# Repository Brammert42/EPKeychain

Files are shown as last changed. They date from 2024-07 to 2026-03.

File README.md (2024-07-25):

# DisplayKeychain
This repository is used to track FW development for Display Keychain using a RP2040 and waveshare Display.

# Manual
## Next image  
Holding the middle button for 4 seconds changes the image on the display to next image in the list.
347458965-2d2ebbd9-4378-4e5e-b3c1-cca8a8e5ecf9

## Previous image
Holding the middle button and the left button (button closet to the small hole) for 4 seconds changes the image on the display to previous image in the list.
347459136-833cc375-673a-45cc-b46e-be061921ad6f

## Uploading new FW  
Get the FW files here:   https://github.com/Brammert42/EPKeychain/tree/main/FW%20version
1: insert push pin in the hole next to the "previous" button untill you feel a "click"  
2: while the push pin is inserted insert the micro USB.  
3: on your PC the keychain will show up as flash drive as RPI-RP2, drag the new FW file into this  
347462579-89d27679-47dc-4f86-8ac1-4f59785b6a21
347464186-8c0baafe-d529-45a7-bd64-d2fc7caff128
347464487-d523694f-2f7c-4718-9145-aeae9413a095

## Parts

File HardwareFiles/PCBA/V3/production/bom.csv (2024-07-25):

Designator | Footprint | Quantity | Value | LCSC Part #
C1, C17, C18, C19, C21, C23, C24, C25, C26, C27, C28, C31, C7 | 0402 | 13 | 100n | C307331
C10, C11, C12, C20, C22, C3, C32, C33, C4, C5, C6, C8, C9 | 0402 | 13 | 1uF | C52923
C13, C14 | 0402 | 2 | 15p | C1548
C15, C16, C2, C29, C30, C34, C35, C36, C37, C38, C39, C40, C41, C42, C43, C44, C45, C46, C47, C48, C49 | 0402 | 21 | 10u | C23733
D1, D2, D3 | D_SOD-123 | 3 | MBR0530 | C8598
D4, D5 | D_SOD-923 | 2 | ESD9B3.3ST5G | C3021104
D6 | D_SOD-323 | 1 | LBAT54HT1G | C12744
J11 | BatteryHolder_Multicomp_BC-2001_1x2032 | 1 | BAT-HLD-001-THM | C2979177
J2 | Hirose_FH12-24S-0.5SH_1x24-1MP_P0.50mm_Horizontal | 1 | Conn_01x24 | C262669
J5 | USB_Micro-B_Wuerth_614105150721_Vertical | 1 | USB_B_Micro | C668588
L1 | 1210 | 1 | 68uH | C295164
Q1, Q3 | SOT-23 | 2 | AO3400A | C20917
Q2 | SOT-23 | 1 | AO3401A | C15127
R1, R10, R13, R14 | 0402 | 4 | 10k | C25744
R11, R9 | 0402 | 2 | 47k | C25792
R2 | 0402 | 1 | 3 | C321178
R4, R6 | 0402 | 2 | 1k | C11702
R5 | 0402 | 1 | DNF | dnf
R7, R8 | 0402 | 2 | 27 | C25100
SW1, SW3, SW6 | SW_SPST_Omron_B3FS-100xP | 3 | SW_Omron_B3FS | C5127964
SW2 | SW_SPST_TL3342 | 1 | SW_MEC_5E | C318884
TP1 | display | 1 | TestPoint | dnf
U1 | SOT-23-5 | 1 | MCP1802x-xx02xOT | C7419952
U4 | SON50P300X200X60-9N | 1 | ZD25WQ32CEIGR | C5258281
U5 | QFN-56-1EP_7x7mm_P0.4mm_EP3.2x3.2mm | 1 | RP2040 | C2040
Y1 | Crystal_SMD_3225-4Pin_3.2x2.5mm | 1 | ABM8-272-T3 | C9002

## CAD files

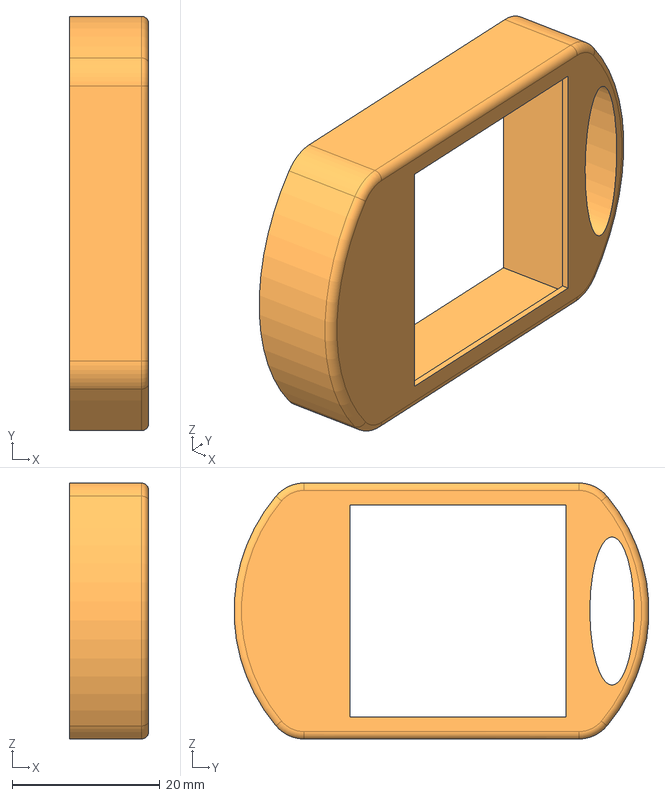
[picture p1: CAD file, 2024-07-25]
HardwareFiles/Enclosure/mainbody.step
10.8 x 56.1 x 34.6 mm

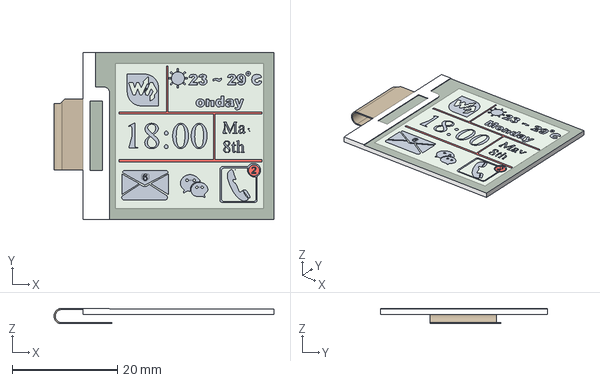
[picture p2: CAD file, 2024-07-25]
HardwareFiles/Enclosure/E-ink display.step
41.8 x 31.8 x 2.92 mm

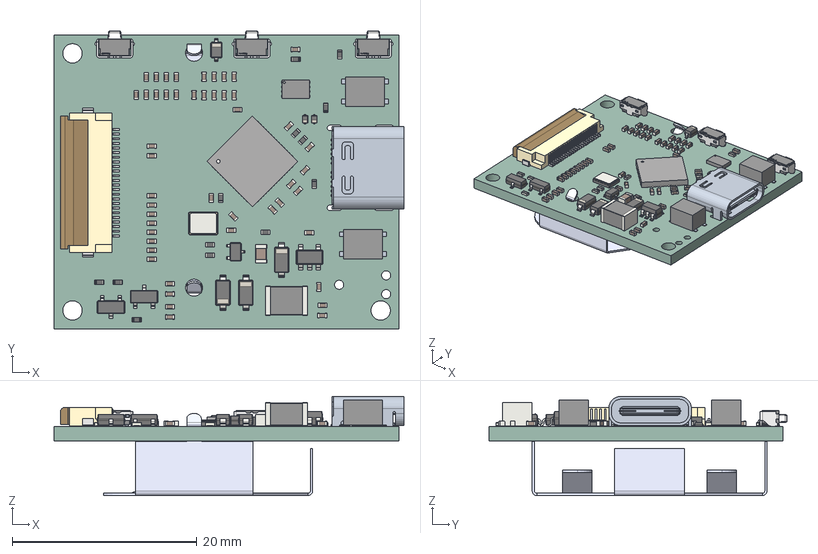
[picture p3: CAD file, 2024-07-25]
HardwareFiles/PCBA/V3/KeyChainv2.step
37.8 x 32.2 x 10.7 mm
C_0402_1005Metric x 48
R_0402_1005Metric x 13
D_SOD_923 x 2
SOT_323_SC_70
D_SOD_123 x 3
ASSEMBLY x 3
D_SOD_323
C_0805_2012Metric
QFN_56_1EP_7x7mm_P04mm_EP32x32mm
SOT_23 x 2
SOT_23_5
Hirose_FH12_xxS_0_5SH_Parametric_v0_1
L_1812_4532Metric
Crystal_SMD_3225-4Pin_3.2x2.5mm
_autosave-KeyChain_PCB

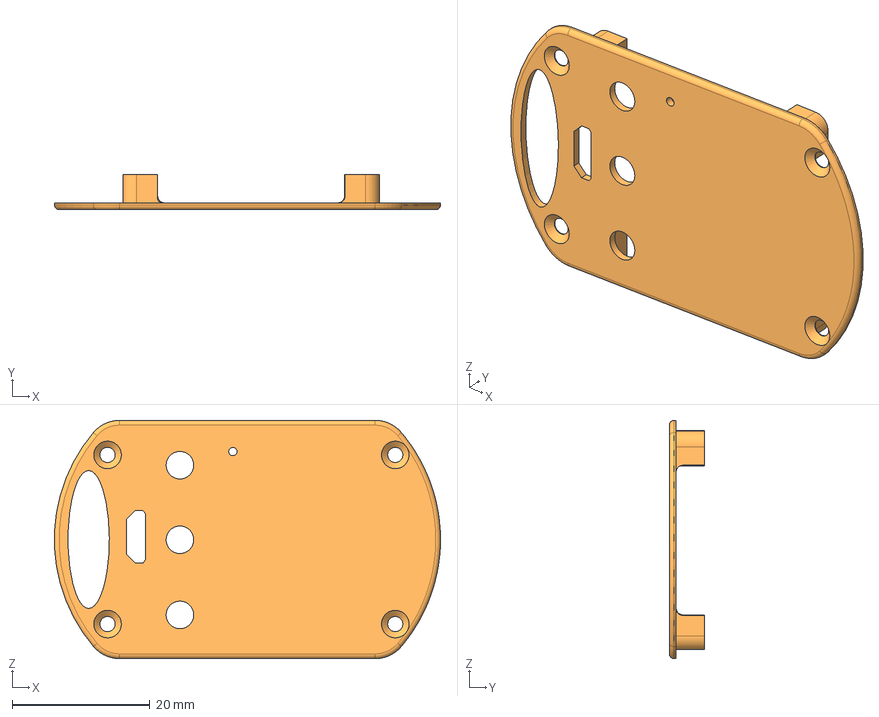
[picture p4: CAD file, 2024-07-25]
HardwareFiles/Enclosure/coverplate.step
56.1 x 5.15 x 34.6 mm

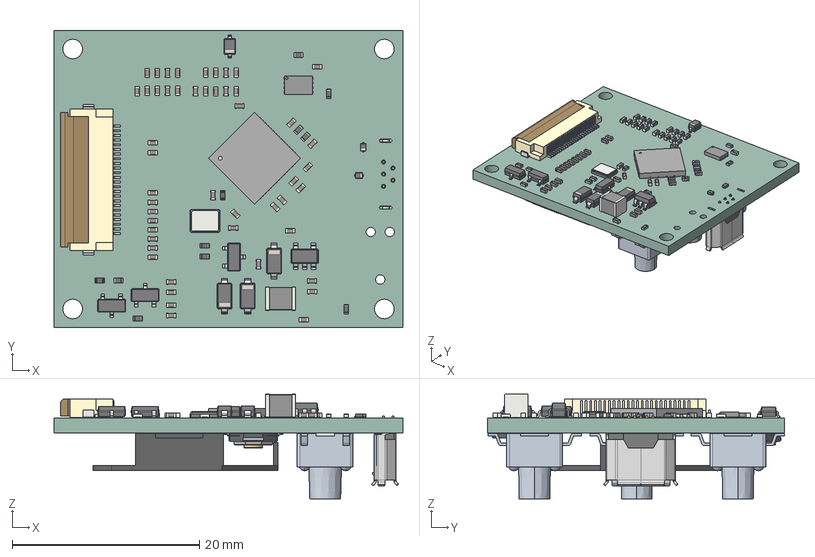
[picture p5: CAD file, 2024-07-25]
HardwareFiles/PCBA/V3/KeyChainv4.step
37.3 x 31.8 x 11.2 mm
C_0402_1005Metric x 49
R_0402_1005Metric x 11
D_SOD_923 x 2
SOT_23 x 3
D_SOD_123 x 3
ASSEMBLY
D_SOD_323
QFN_56_1EP_7x7mm_P04mm_EP32x32mm
SOT_23_5
Hirose_FH12_xxS_0_5SH_Parametric_v0_1
L_1210_3225Metric
Crystal_SMD_3225-4Pin_3.2x2.5mm
C-2-1977223-0 x 3
SW_SPST_TL3342
_autosave-KeyChain_PCB

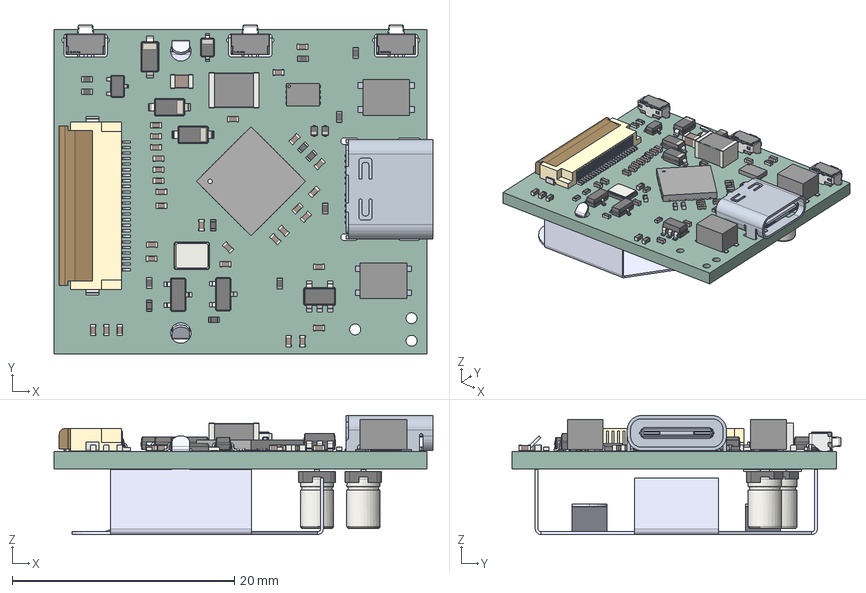
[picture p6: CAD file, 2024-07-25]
HardwareFiles/PCBA/V3/KeyChain.step
34.1 x 29.7 x 10.7 mm
C_0402_1005Metric x 30
R_0402_1005Metric x 13
D_SOD_923 x 2
SOT_323_SC_70
D_SOD_123 x 3
ASSEMBLY x 3
D_SOD_323
C_0805_2012Metric
QFN_56_1EP_7x7mm_P04mm_EP32x32mm
SOT_23 x 2
SOT_23_5
Hirose_FH12_xxS_0_5SH_Parametric_v0_1
L_1812_4532Metric
Crystal_SMD_3225-4Pin_3.2x2.5mm
CP_Elec_3x53 x 2
_autosave-KeyChain_PCB

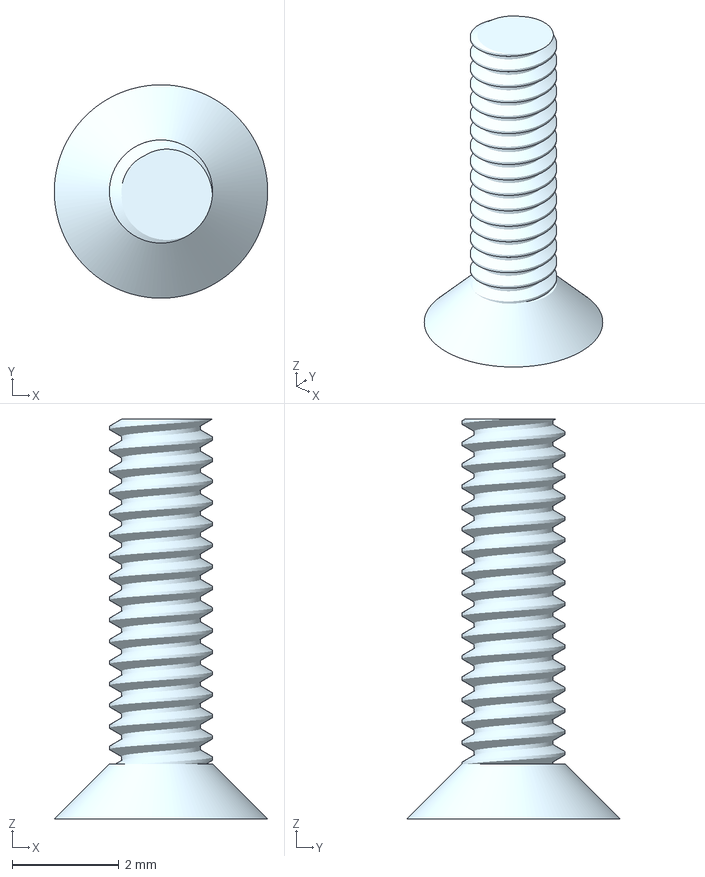
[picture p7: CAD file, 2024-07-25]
HardwareFiles/Enclosure/m2 6mm screw.step
4.00 x 4.00 x 7.50 mm

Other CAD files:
HardwareFiles/PCBA/V3/KeyChainv3cr2032buttonchange.step

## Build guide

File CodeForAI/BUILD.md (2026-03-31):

# BTC KeyChain — Pico SDK Build Guide

## Prerequisites

### 1. Install the Pico SDK

```bash
# Linux / macOS
git clone https://github.com/raspberrypi/pico-sdk.git ~/pico-sdk
cd ~/pico-sdk
git submodule update --init
export PICO_SDK_PATH=~/pico-sdk
```

Add the export to your `~/.bashrc` or `~/.zshrc` so it persists.

### 2. Install build tools

**Linux (Ubuntu/Debian):**
```bash
sudo apt install cmake gcc-arm-none-eabi libnewlib-arm-none-eabi build-essential
```

**macOS:**
```bash
brew install cmake
brew install --cask gcc-arm-embedded
```

**Windows:**
Use the [Raspberry Pi Pico Windows Installer](https://github.com/raspberrypi/pico-setup-windows/releases)
which installs everything including CMake and the ARM toolchain.

---

## Project structure

```
btckeychain/
├── CMakeLists.txt
├── BUILD.md
├── src/
│   ├── main.cpp            — main loop, replaces BTCKeyChain.ino
│   ├── config_fs.cpp/h     — FAT12 disk, flash storage, USB MSC
│   ├── bip32.cpp/h         — BIP32 key derivation
│   ├── btcaddr.cpp/h       — address encoding (legacy/segwit/taproot)
│   ├── epd_qr.cpp/h        — QR → EPD framebuffer renderer
│   ├── qrcodegen.c/h       — Nayuki QR library (see below)
│   ├── tusb_config.h       — TinyUSB: MSC only, no CDC
│   └── usb_descriptors.c   — USB device/config/string descriptors
└── waveshare_epd/
    ├── epd1in54_V2.cpp/h   — Waveshare 1.54" e-ink driver
    ├── epdif.cpp/h         — SPI/GPIO interface (Pico SDK)
    ├── epdpaint.cpp/h      — paint/framebuffer library
    └── font*.c / fonts.h   — bitmap fonts
```

---

## One step before building — add the QR library

Download these two files from https://github.com/nayuki/QR-Code-generator/tree/master/c

- `qrcodegen.h`
- `qrcodegen.c`

**Replace** `src/qrcodegen.c` (the stub) and `src/qrcodegen.h` with the real files.

---

## Build

```bash
cd btckeychain
mkdir build && cd build
cmake .. -DPICO_SDK_PATH=$PICO_SDK_PATH
make -j4
```

Output: `build/btckeychain.uf2`

---

## Flash

1. Hold **BOOTSEL** on the Pico while plugging in USB
2. It mounts as a drive called **RPI-RP2**
3. Drag and drop `btckeychain.uf2` onto it
4. It reboots automatically

---

## Flash layout

The firmware uses raw flash for persistence (no filesystem library needed):

```
0x00000000  ┌─────────────────────────┐
            │   Sketch / firmware     │  up to ~1.75 MB
            ├─────────────────────────┤
0x001D8000  │   Address index         │  4 KB (1 flash sector)
            ├─────────────────────────┤
0x001E0000  │   FAT12 disk image      │  128 KB  (config.txt lives here)
            └─────────────────────────┘
0x00200000  (end of 2 MB flash)
```

---

## Key differences from Arduino version

| Arduino | Pico SDK |
|---|---|
| `EEPROM.begin()` / `.write()` | `flash_range_program()` directly |
| `LittleFS` | Raw flash — simpler, one less dependency  |
| `SPI.begin(true)` | `spi_init(spi0, ...)` + `gpio_set_function` |
| `delay()` | `sleep_ms()` |
| `millis()` | `get_absolute_time()` / `absolute_time_diff_us()` |
| `digitalWrite()` | `gpio_put()` |
| `digitalRead()` | `gpio_get()` |
| `pinMode(INPUT_PULLUP)` | `gpio_pull_up()` |
| USB stack starts before main  | `tusb_init()` called explicitly — you control when |

---

## Why battery works now

In the Arduino version, the Earle Philhower core starts the USB stack on core1
**before** `setup()` runs. There is no supported way to prevent this.

In the Pico SDK version:
1. The program starts, inits the display, shows "Checking USB..."
2. `configFSBegin()` reads bit 19 of `USB_SIE_STATUS` — a raw hardware register
3. If VBUS is not present (battery): skips `tusb_init()` entirely and returns immediately
4. If VBUS is present (USB): calls `tusb_init()`, waits for mount, makes drive visible

No USB stack activity ever occurs on battery boot.

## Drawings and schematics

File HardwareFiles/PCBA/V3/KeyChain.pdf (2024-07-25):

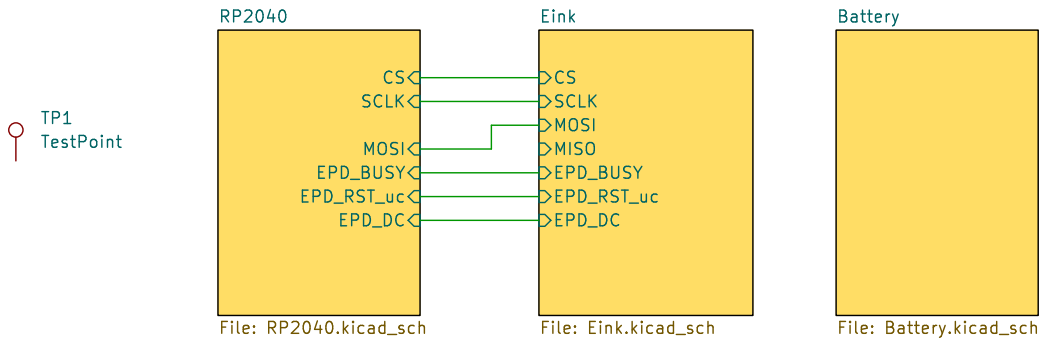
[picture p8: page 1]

Id: 1/4 Title: File: KeyChain.kicad_sch Sheet: /

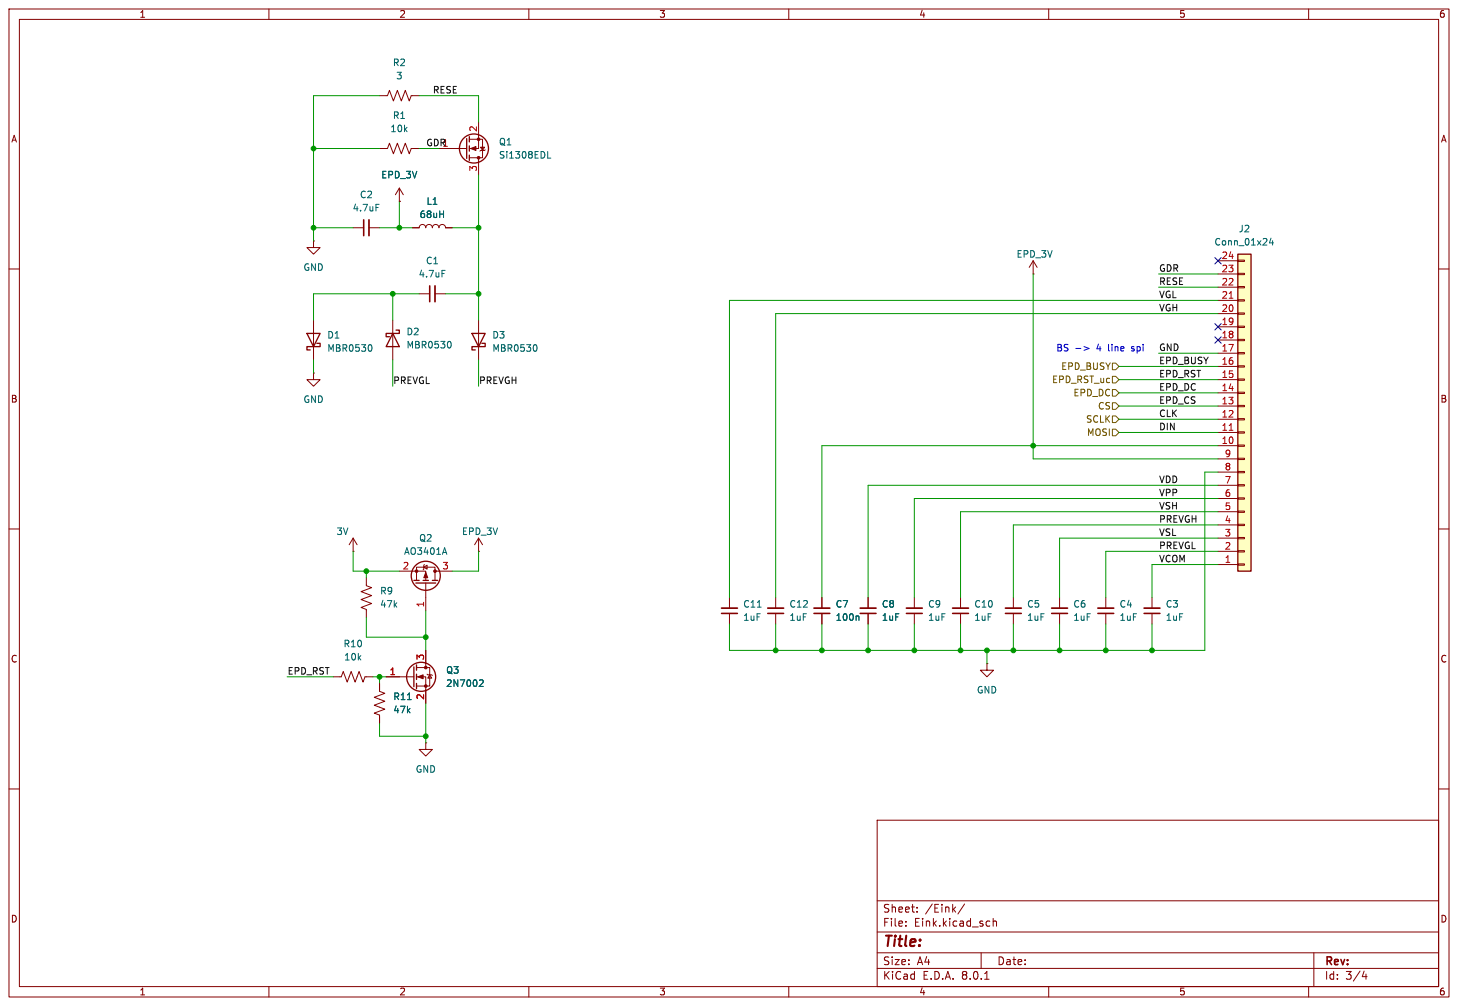
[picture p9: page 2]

PREVGL RESE GDR VGL VDD 19 18 17 EPD_BUSY 16 15 EPD_RST_uc CS EPD_DC 14 EPD_DC EPD_CS 13 CLK 12 DIN 11 10

VGH 20

VPP | 6

PREVGH | 4

VCOM | 1

Id: 3/4 Title: File: Eink.kicad_sch Sheet: /Eink/

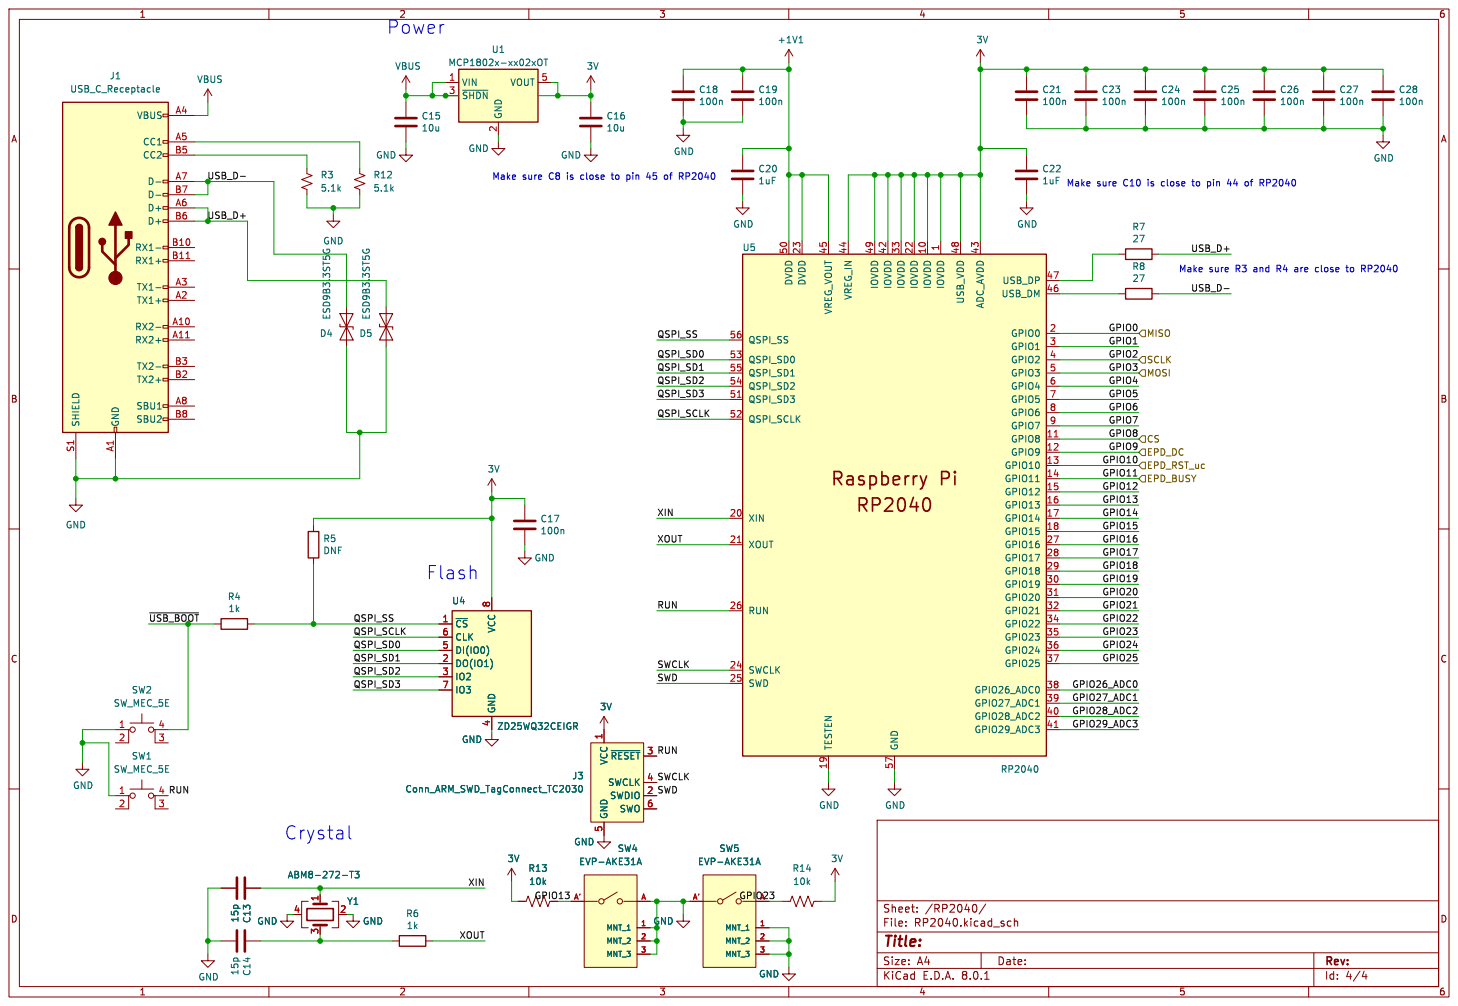
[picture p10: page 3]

1 IOVDD 10 GPIO8 11 GPIO9 12 GPIO10 13 GPIO11 14 GPIO12 15 GPIO13 16 GPIO14 17 GPIO15 18 TESTEN 19 GPIO0 2 XIN 20 XOUT 21 IOVDD 22 DVDD 23 SWCLK 24 SWD 25 RUN 26 GPIO16 27 GPIO17 28 GPIO18 29 GPIO1 3 GPIO19 30 GPIO20 31 GPIO21 32 IOVDD 33 GPIO22 34 GPIO23 35 GPIO24 36 GPIO25 37 GPIO26_ADC0 38 GPIO27_ADC1 39 GPIO2 4 GPIO28_ADC2 40 GPIO29_ADC3 41 IOVDD 42 ADC_AVDD 43 VREG_IN 44 VREG_VOUT 45 USB_DM 46 USB_DP 47 USB_VDD 48 IOVDD 49 GPIO3 5 DVDD 50 QSPI_SD3 51 QSPI_SCLK 52 QSPI_SD0 53 QSPI_SD2 54 QSPI_SD1 55 QSPI_SS 56 GND 57 GPIO4 6 GPIO5 7 GPIO6 8 GPIO7 9 U5 RP2040 15p C13 GND

Id: 4/4 Title: File: RP2040.kicad_sch Sheet: /RP2040/ 3V

1 SWDIO 2 ~{RESET}3 SWCLK 4 GND

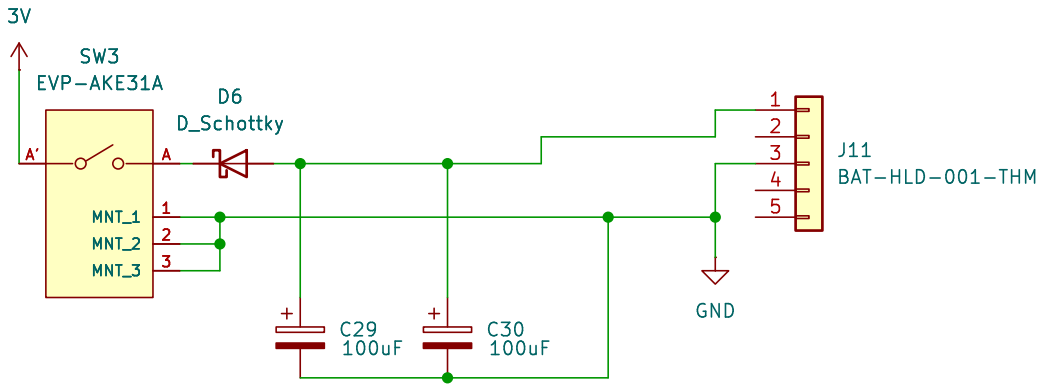
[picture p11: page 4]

Id: 5/4 Title: File: Battery.kicad_sch Sheet: /Battery/

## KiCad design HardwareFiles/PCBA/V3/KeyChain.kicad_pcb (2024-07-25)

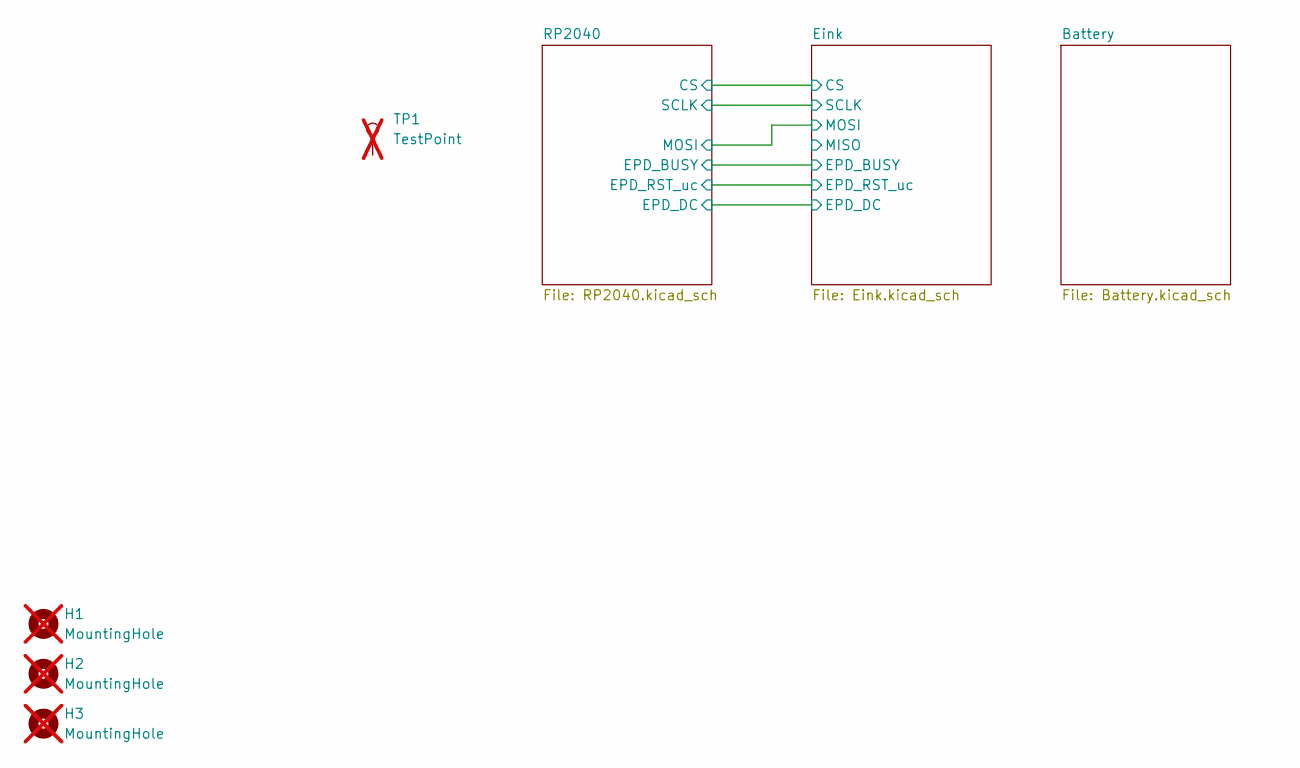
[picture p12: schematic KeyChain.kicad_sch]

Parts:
H1, H2, H3: MountingHole; MountingHole_2.1mm; not fitted
TP1: TestPoint; display; MPN dnf; not fitted

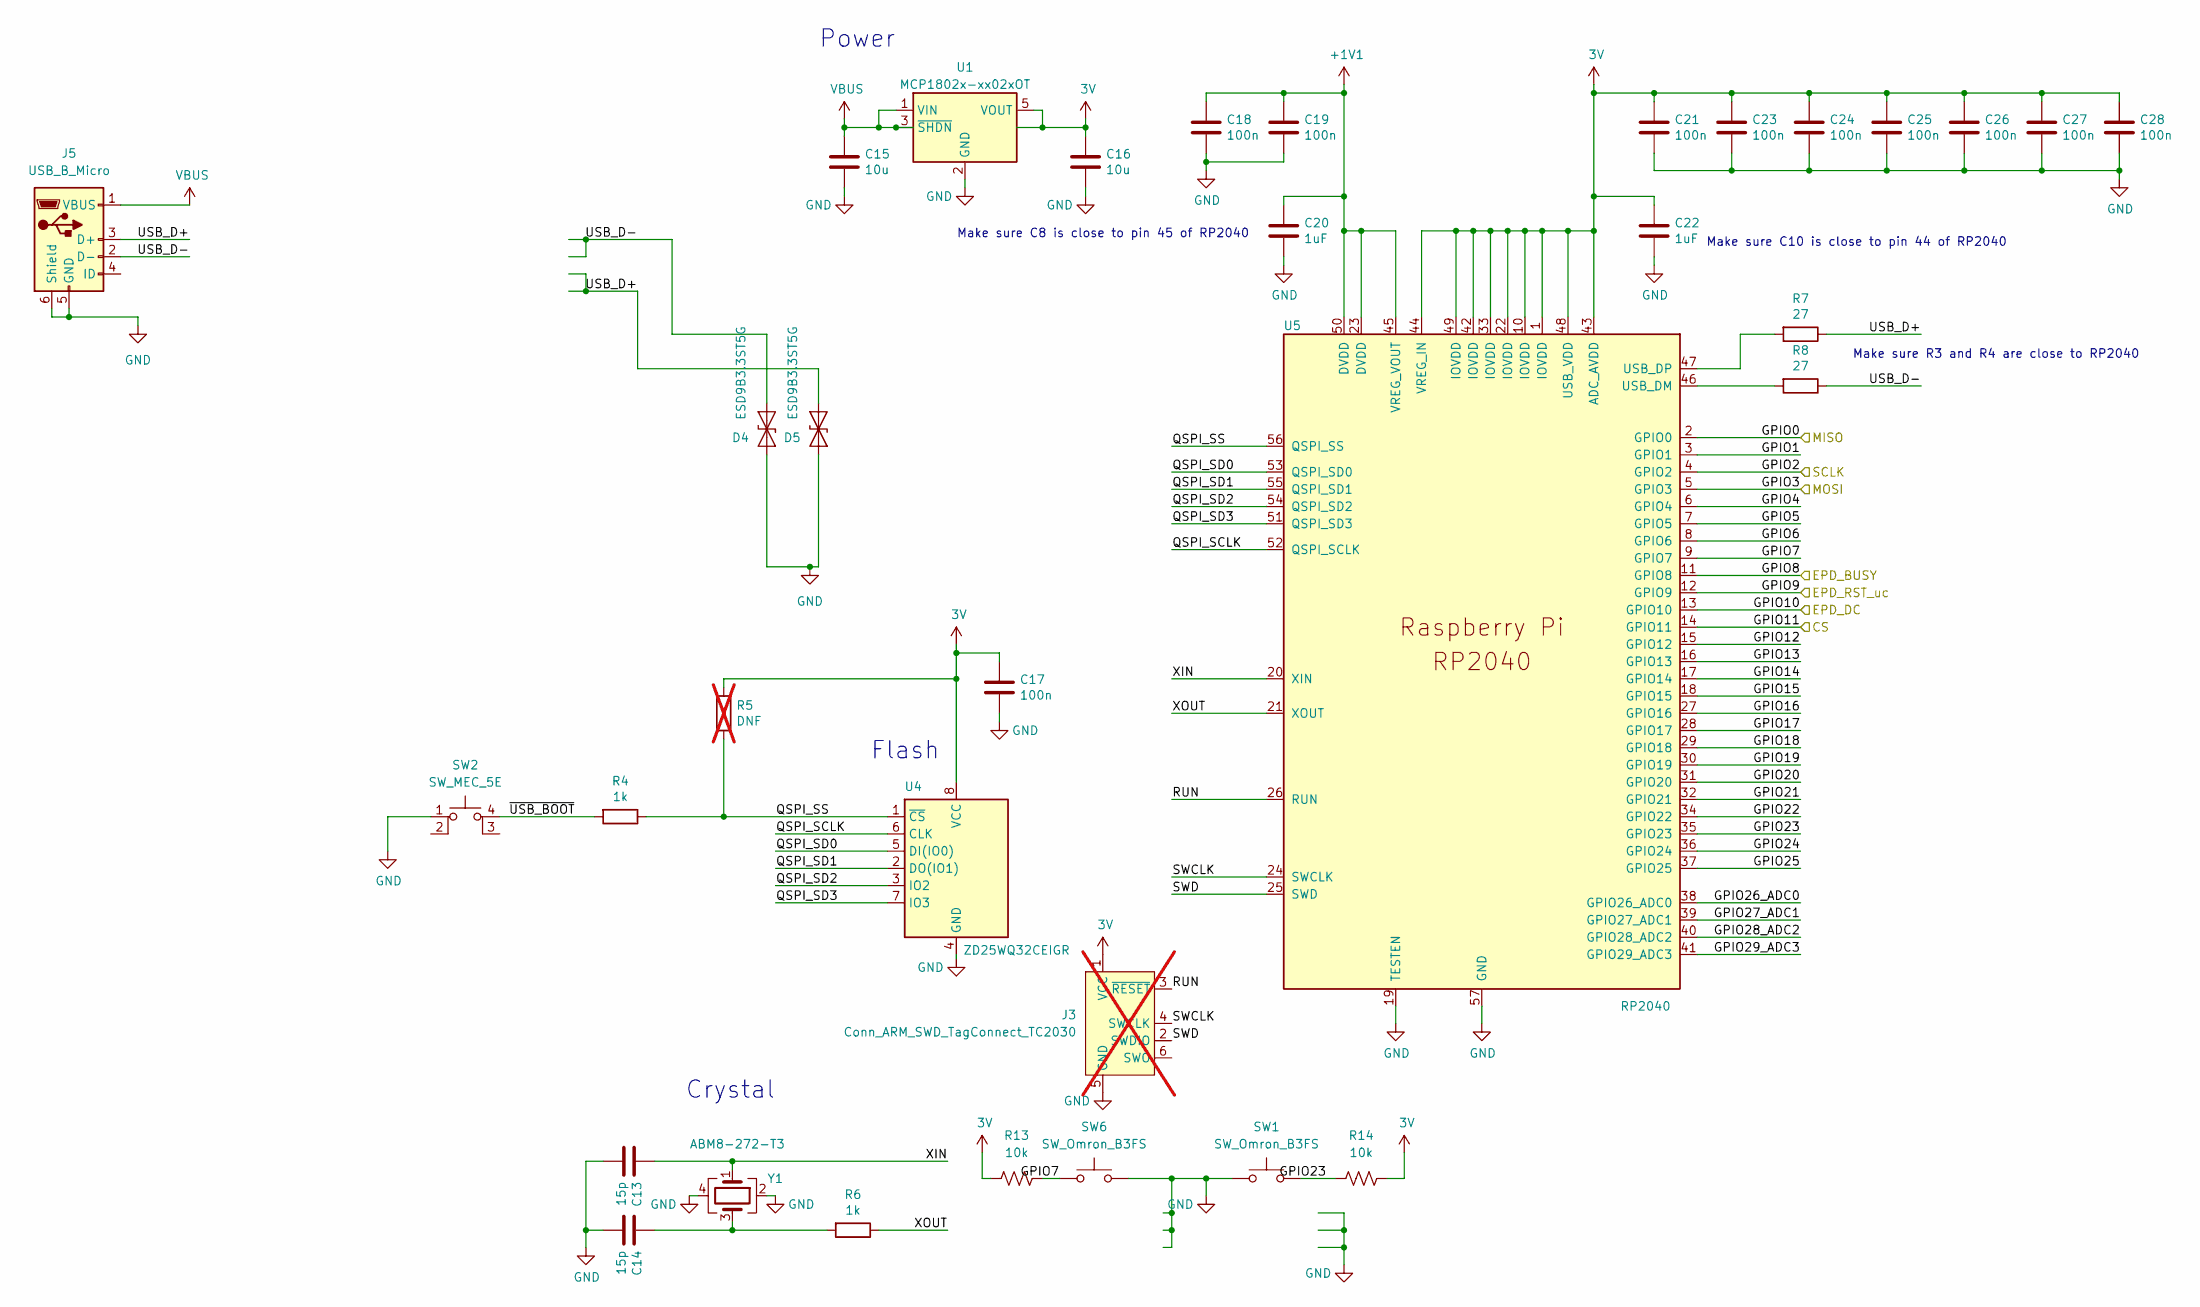
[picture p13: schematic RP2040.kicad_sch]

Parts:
C13, C14: 15p; C_0402_1005Metric; MPN C1548
C15, C16: 10u; C_0402_1005Metric; MPN C23733
C17, C18, C19, C21, C23, C24, C25, C26, C27, C28: 100n; C_0402_1005Metric; MPN C307331
C20, C22: 1uF; C_0402_1005Metric; MPN C52923
D4, D5: ESD9B3.3ST5G; D_SOD-923; MPN C3021104
J3: Conn_ARM_SWD_TagConnect_TC2030; Tag-Connect_TC2030-IDC-NL_2x03_P1.27mm_Vertical; not fitted
J5: USB_B_Micro; USB_Micro-B_Wuerth_614105150721_Vertical; MPN C668588
R4, R6: 1k; R_0402_1005Metric; MPN C11702
R5: DNF; R_0402_1005Metric; MPN dnf; not fitted
R7, R8: 27; R_0402_1005Metric; MPN C25100
R13, R14: 10k; R_0402_1005Metric; MPN C25744
SW1, SW6: SW_Omron_B3FS; SW_SPST_Omron_B3FS-100xP; MPN C5127964
SW2: SW_MEC_5E; SW_SPST_TL3342; MPN C318884
U1: MCP1802x-xx02xOT; SOT-23-5; MPN C7419952
U4: ZD25WQ32CEIGR; SON50P300X200X60-9N; MPN C5258281
U5: RP2040; QFN-56-1EP_7x7mm_P0.4mm_EP3.2x3.2mm; MPN C2040
Y1: ABM8-272-T3; Crystal_SMD_3225-4Pin_3.2x2.5mm; MPN C9002

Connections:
3V: C16.1, C17.1, C21.1, C22.1, C23.1, C24.1, C25.1, C26.1, C27.1, C28.1, J3.1 (VCC), R5.1, R13.1, R14.2, U1.4 (NC), U1.5 (VOUT), U4.8 (VCC), U5.1 (IOVDD), U5.10 (IOVDD), U5.22 (IOVDD), U5.33 (IOVDD), U5.42 (IOVDD), U5.43 (ADC_AVDD), U5.44 (VREG_IN), U5.48 (USB_VDD), U5.49 (IOVDD); also elsewhere on the board
+1V1: C18.1, C19.1, C20.1, U5.23 (DVDD), U5.45 (VREG_VOUT), U5.50 (DVDD)
/Eink/CLK: U5.4 (GPIO2); also elsewhere on the board
/Eink/DIN: U5.5 (GPIO3); also elsewhere on the board
/Eink/EPD_BUSY: U5.11 (GPIO8); also elsewhere on the board
/Eink/EPD_CS: U5.14 (GPIO11); also elsewhere on the board
/Eink/EPD_DC: U5.13 (GPIO10); also elsewhere on the board
/Eink/EPD_RST: U5.12 (GPIO9); also elsewhere on the board
/RP2040/GPIO0: U5.2 (GPIO0)
/RP2040/GPIO1: U5.3 (GPIO1)
/RP2040/GPIO4: U5.6 (GPIO4)
/RP2040/GPIO5: U5.7 (GPIO5)
/RP2040/GPIO6: U5.8 (GPIO6)
/RP2040/GPIO7: R13.2, SW6.1, U5.9 (GPIO7)
/RP2040/GPIO12: U5.15 (GPIO12)
/RP2040/GPIO13: U5.16 (GPIO13)
/RP2040/GPIO14: U5.17 (GPIO14)
/RP2040/GPIO15: U5.18 (GPIO15)
/RP2040/GPIO16: U5.27 (GPIO16)
/RP2040/GPIO17: U5.28 (GPIO17)
/RP2040/GPIO18: U5.29 (GPIO18)
/RP2040/GPIO19: U5.30 (GPIO19)
/RP2040/GPIO20: U5.31 (GPIO20)
/RP2040/GPIO21: U5.32 (GPIO21)
/RP2040/GPIO22: U5.34 (GPIO22)
/RP2040/GPIO23: R14.1, SW1.2, U5.35 (GPIO23)
/RP2040/GPIO24: U5.36 (GPIO24)
/RP2040/GPIO25: U5.37 (GPIO25)
/RP2040/GPIO26_ADC0: U5.38 (GPIO26_ADC0)
/RP2040/GPIO27_ADC1: U5.39 (GPIO27_ADC1)
/RP2040/GPIO28_ADC2: U5.40 (GPIO28_ADC2)
/RP2040/GPIO29_ADC3: U5.41 (GPIO29_ADC3)
/RP2040/QSPI_SCLK: U4.6 (CLK), U5.52 (QSPI_SCLK)
/RP2040/QSPI_SD0: U4.5 (DI(IO0)), U5.53 (QSPI_SD0)
/RP2040/QSPI_SD1: U4.2 (DO(IO1)), U5.55 (QSPI_SD1)
/RP2040/QSPI_SD2: U4.3 (IO2), U5.54 (QSPI_SD2)
/RP2040/QSPI_SD3: U4.7 (IO3), U5.51 (QSPI_SD3)
/RP2040/QSPI_SS: R4.1, R5.2, U4.1 (~CS), U5.56 (QSPI_SS)
/RP2040/RUN: J3.3 (~RESET), U5.26 (RUN)
/RP2040/SWCLK: J3.4 (SWCLK), U5.24 (SWCLK)
/RP2040/SWD: J3.2 (SWDIO), U5.25 (SWD)
/RP2040/USB_D+: D5.1 (A1), J5.3 (D+), R7.1
/RP2040/USB_D-: D4.1 (A1), J5.2 (D-), R8.1
/RP2040/XIN: C13.1, U5.20 (XIN), Y1.1
/RP2040/XOUT: R6.1, U5.21 (XOUT)
/RP2040/~USB_BOOT: R4.2, SW2.4 (A)
GND: C13.2, C14.2, C15.2, C16.2, C17.2, C18.2, C19.2, C20.2, C21.2, C22.2, C23.2, C24.2, C25.2, C26.2, C27.2, C28.2, D4.2 (A2), D5.2 (A2), J3.5 (GND), J5.5 (GND), J5.6 (Shield), SW1.1, SW2.1, SW6.2, U1.2 (GND), U4.4 (GND), U5.19 (TESTEN), U5.57 (GND), Y1.2, Y1.4; also elsewhere on the board
unnamed: C14.1, R6.2, Y1.3
unnamed: R8.2, U5.46 (USB_DM)
unnamed: R7.2, U5.47 (USB_DP)
VBUS: C15.1, J5.1 (VBUS), U1.1 (VIN), U1.3 (~SHDN)

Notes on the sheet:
Make sure R3 and R4 are close to RP2040
Power
Crystal
Make sure C10 is close to pin 44 of RP2040
Flash
Make sure C8 is close to pin 45 of RP2040

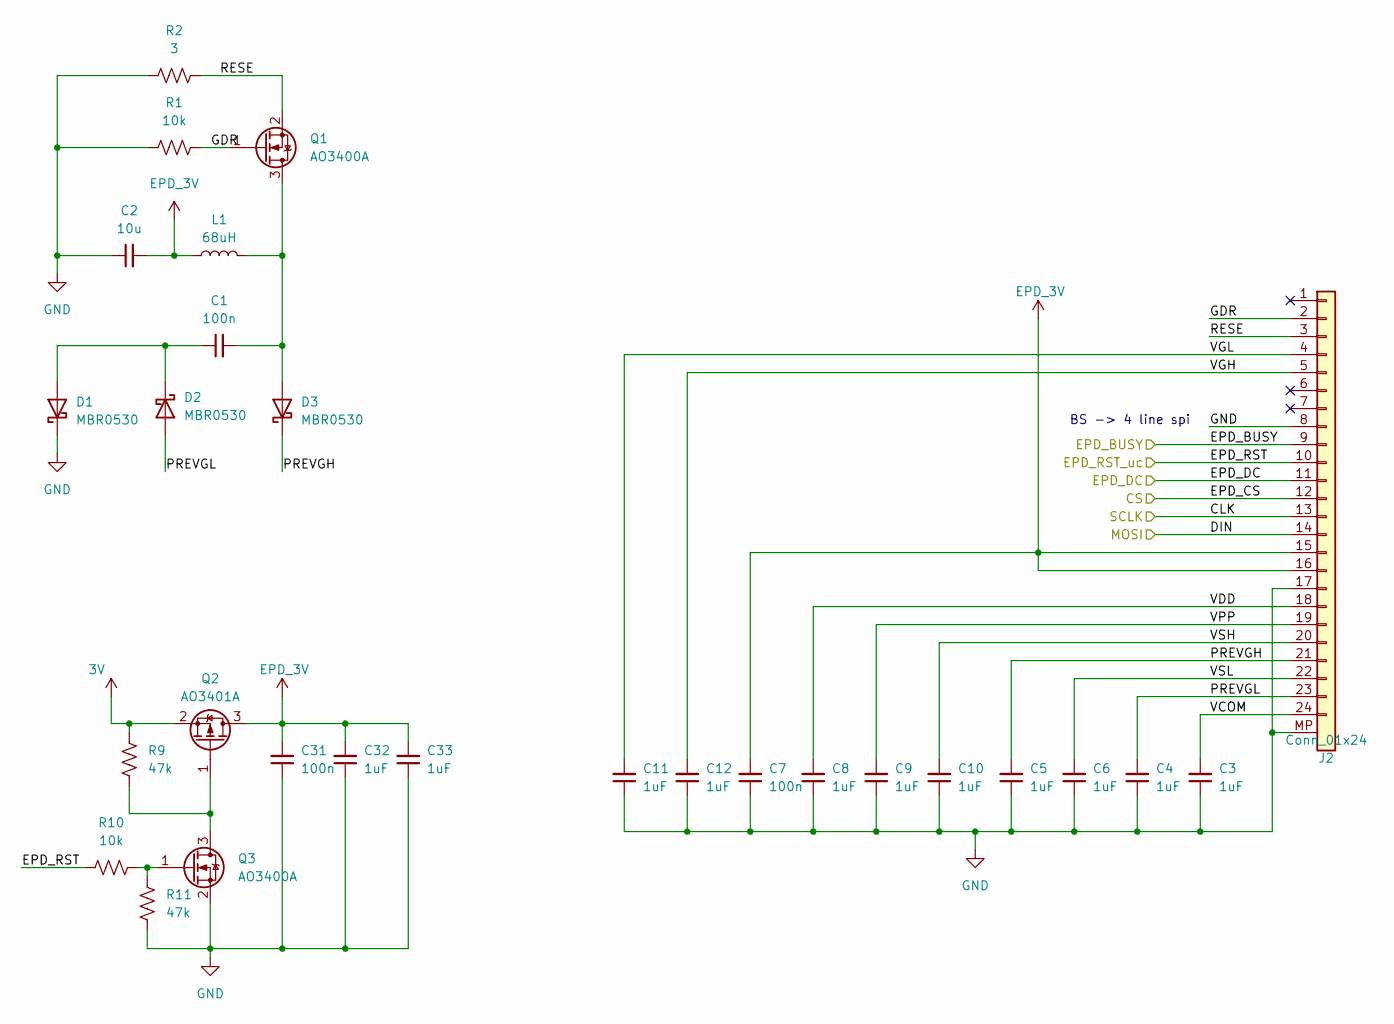
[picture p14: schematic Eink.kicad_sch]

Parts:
C1, C7, C31: 100n; C_0402_1005Metric; MPN C307331
C2: 10u; C_0402_1005Metric; MPN C23733
C3, C4, C5, C6, C8, C9, C10, C11, C12, C32, C33: 1uF; C_0402_1005Metric; MPN C52923
D1, D2, D3: MBR0530; D_SOD-123; MPN C8598
J2: Conn_01x24; Hirose_FH12-24S-0.5SH_1x24-1MP_P0.50mm_Horizontal; MPN C262669
L1: 68uH; L_1210_3225Metric; MPN C295164
Q1, Q3: AO3400A; SOT-23; MPN C20917
Q2: AO3401A; SOT-23; MPN C15127
R1, R10: 10k; R_0402_1005Metric; MPN C25744
R2: 3; R_0402_1005Metric; MPN C321178
R9, R11: 47k; R_0402_1005Metric; MPN C25792

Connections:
3V: Q2.2 (S), R9.2; also elsewhere on the board
/Eink/CLK: J2.13; also elsewhere on the board
/Eink/DIN: J2.14; also elsewhere on the board
/Eink/EPD_BUSY: J2.9; also elsewhere on the board
/Eink/EPD_CS: J2.12; also elsewhere on the board
/Eink/EPD_DC: J2.11; also elsewhere on the board
/Eink/EPD_RST: J2.10, R10.2; also elsewhere on the board
/Eink/GDR: J2.2, Q1.1 (G), R1.2
/Eink/PREVGH: C5.2, D3.1 (K), J2.21
/Eink/PREVGL: C4.2, D2.2 (A), J2.23
/Eink/RESE: J2.3, Q1.2 (S), R2.2
/Eink/VCOM: C3.2, J2.24
/Eink/VDD: C8.2, J2.18
/Eink/VGH: C12.2, J2.5
/Eink/VGL: C11.2, J2.4
/Eink/VPP: C9.2, J2.19
/Eink/VSH: C10.2, J2.20
/Eink/VSL: C6.2, J2.22
EPD_3V: C2.2, C7.2, C31.2, C32.2, C33.2, J2.15, J2.16, L1.1, Q2.3 (D)
GND: C2.1, C3.1, C4.1, C5.1, C6.1, C7.1, C8.1, C9.1, C10.1, C11.1, C12.1, C31.1, C32.1, C33.1, D1.1 (K), J2.8, J2.17, J2.MP, Q3.2 (S), R1.1, R2.1, R11.1; also elsewhere on the board
unnamed: C1.1, D1.2 (A), D2.1 (K)
unnamed: C1.2, D3.2 (A), L1.2, Q1.3 (D)
unnamed: Q2.1 (G), Q3.3 (D), R9.1
unnamed: Q3.1 (G), R10.1, R11.2

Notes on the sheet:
BS -> 4 line spi

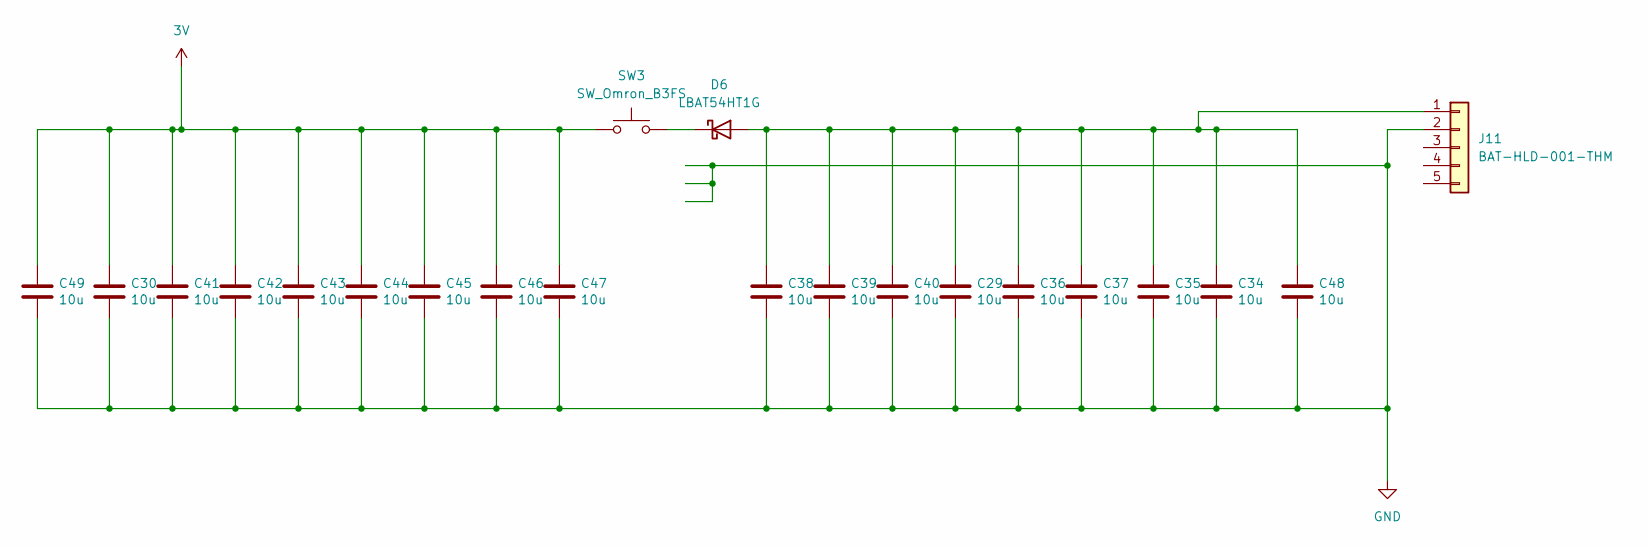
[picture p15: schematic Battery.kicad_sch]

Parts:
C29, C30, C34, C35, C36, C37, C38, C39, C40, C41, C42, C43, C44, C45, C46, C47, C48, C49: 10u; C_0402_1005Metric; MPN C23733
D6: LBAT54HT1G; D_SOD-323; MPN C12744
J11: BAT-HLD-001-THM; BatteryHolder_Multicomp_BC-2001_1x2032; MPN C2979177
SW3: SW_Omron_B3FS; SW_SPST_Omron_B3FS-100xP; MPN C5127964

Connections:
3V: C30.1, C41.1, C42.1, C43.1, C44.1, C45.1, C46.1, C47.1, C49.1, SW3.1; also elsewhere on the board
GND: C29.2, C30.2, C34.2, C35.2, C36.2, C37.2, C38.2, C39.2, C40.2, C41.2, C42.2, C43.2, C44.2, C45.2, C46.2, C47.2, C48.2, C49.2, J11.2; also elsewhere on the board
unnamed: C29.1, C34.1, C35.1, C36.1, C37.1, C38.1, C39.1, C40.1, C48.1, D6.2 (A), J11.1
unnamed: D6.1 (K), SW3.2

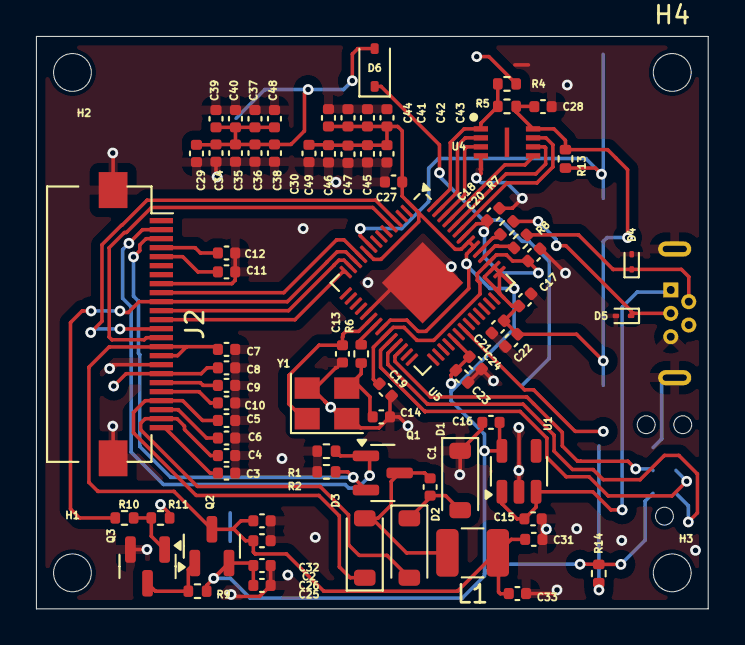
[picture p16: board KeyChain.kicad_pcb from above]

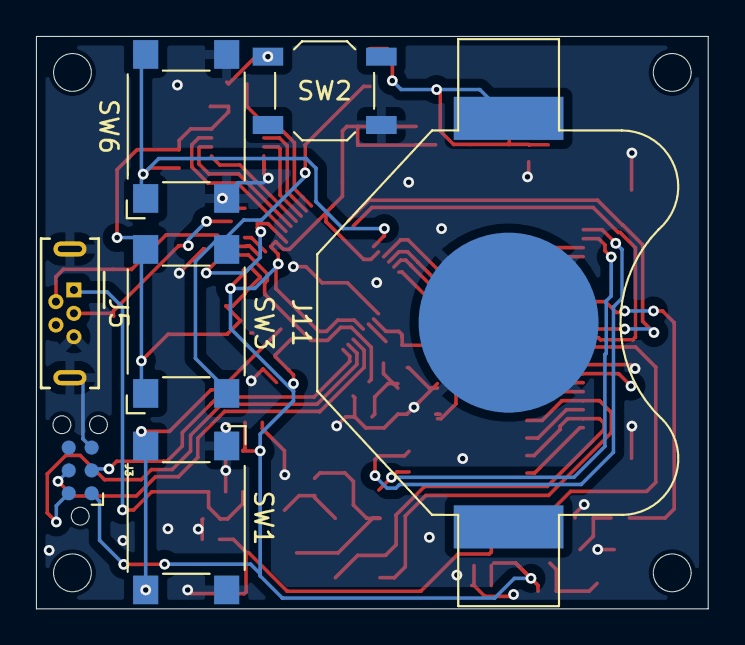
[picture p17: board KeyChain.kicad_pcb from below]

Board: 2 copper layers, 37.3 x 31.8 mm, 88 parts (7 on the bottom side), 47 nets.

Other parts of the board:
H4: MountingHole; MountingHole_2.1mm

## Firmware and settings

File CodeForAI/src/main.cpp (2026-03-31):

/*
 * main.cpp — BTC KeyChain firmware (Pico SDK)
 *
 * Hardware:
 *   EPD RST=9  DC=10  CS=11  BUSY=8  PWR=6
 *   SPI RX=0  SCK=2  TX=3
 *   Button A = GPIO13  (next address, active LOW)
 *   Button B = GPIO23  (reset to index 0, active LOW)
 *   SW3 = mechanical CR2032 power switch
 *
 * Build:
 *   mkdir build && cd build
 *   cmake .. -DPICO_SDK_PATH=/path/to/pico-sdk
 *   make -j4
 */

#include "pico/stdlib.h"
#include "hardware/spi.h"
#include "hardware/flash.h"
#include "hardware/sync.h"
#include "pico/time.h"

#include "epd1in54_V2.h"
#include "epdpaint.h"
#include "bip32.h"
#include "btcaddr.h"
#include "qrcodegen.h"
#include "epd_qr.h"
#include "config_fs.h"

// Display color constants
#define COLORED   0
#define UNCOLORED 1

#include <string.h>
#include <stdio.h>

// ── Pin definitions ───────────────────────────────────────────────────────────
#define BTN_A       13
#define BTN_B       23
#define HOLD_MS     800

// ── EEPROM-style index persistence in flash ───────────────────────────────────
// Store address index in the 4KB sector just below the disk image area.
// config_fs uses the last 256KB; we use the sector just before that.
#define INDEX_FLASH_OFFSET  (PICO_FLASH_SIZE_BYTES - 256*1024 - FLASH_SECTOR_SIZE)
#define MAGIC_COOKIE        0xB7C0FFEEu

static void save_index(uint32_t idx) {
    // Pack: [magic 4 bytes][index 4 bytes][0xFF padding...]
    static uint8_t buf[FLASH_SECTOR_SIZE];
    memset(buf, 0xFF, sizeof(buf));
    buf[0] = (MAGIC_COOKIE >> 24) & 0xFF;
    buf[1] = (MAGIC_COOKIE >> 16) & 0xFF;
    buf[2] = (MAGIC_COOKIE >>  8) & 0xFF;
    buf[3] = (MAGIC_COOKIE      ) & 0xFF;
    buf[4] = (idx >> 24) & 0xFF;
    buf[5] = (idx >> 16) & 0xFF;
    buf[6] = (idx >>  8) & 0xFF;
    buf[7] = (idx      ) & 0xFF;

    uint32_t ints = save_and_disable_interrupts();
    flash_range_erase(INDEX_FLASH_OFFSET, FLASH_SECTOR_SIZE);
    flash_range_program(INDEX_FLASH_OFFSET, buf, FLASH_SECTOR_SIZE);
    restore_interrupts(ints);
}

static uint32_t load_index(void) {
    const uint8_t* p = (const uint8_t*)(XIP_BASE + INDEX_FLASH_OFFSET);
    uint32_t magic = ((uint32_t)p[0]<<24)|((uint32_t)p[1]<<16)|
                     ((uint32_t)p[2]<<8) |((uint32_t)p[3]);
    if (magic != MAGIC_COOKIE) return 0;
    return ((uint32_t)p[4]<<24)|((uint32_t)p[5]<<16)|
           ((uint32_t)p[6]<<8) |((uint32_t)p[7]);
}

// ── Display helpers ───────────────────────────────────────────────────────────
static Epd epd;

static void show_text(const char* line1,
                      const char* line2 = nullptr,
                      const char* line3 = nullptr) {
    unsigned char buf[200*200/8];
    memset(buf, 0xFF, sizeof(buf));
    Paint paint(buf, 200, 200);
    paint.SetRotate(ROTATE_0);
    if (line1) paint.DrawStringAt(10, 10, line1, &Font16, COLORED);
    if (line2) paint.DrawStringAt(10, 40, line2, &Font12, COLORED);
    if (line3) paint.DrawStringAt(10, 60, line3, &Font12, COLORED);
    epd.Display(buf);
}

static void show_setup_screen(void) {
    unsigned char buf[200*200/8];
    memset(buf, 0xFF, sizeof(buf));
    Paint paint(buf, 200, 200);
    paint.SetRotate(ROTATE_0);
    paint.DrawStringAt(10,  10, "BTC KeyChain",    &Font16, COLORED);
    paint.DrawStringAt(10,  40, "No config found.", &Font12, COLORED);
    paint.DrawStringAt(10,  60, "Plug in USB and",  &Font12, COLORED);
    paint.DrawStringAt(10,  76, "edit config.txt",  &Font12, COLORED);
    paint.DrawStringAt(10, 100, "xpub=YOUR_KEY",    &Font12, COLORED);
    paint.DrawStringAt(10, 116, "type=84",           &Font12, COLORED);
    epd.Display(buf);
}

static void show_address(const char* address) {
    uint8_t qrBuf[qrcodegen_BUFFER_LEN_MAX];
    uint8_t tmpBuf[qrcodegen_BUFFER_LEN_MAX];
    bool ok = qrcodegen_encodeText(
        address, tmpBuf, qrBuf,
        qrcodegen_Ecc_MEDIUM,
        qrcodegen_VERSION_MIN, qrcodegen_VERSION_MAX,
        qrcodegen_Mask_AUTO, true);
    if (!ok) return;
    unsigned char buf[200*200/8];
    renderQRToEPD(qrBuf, buf, 200, 200);
    epd.Display(buf);
}

// ── Address derivation ────────────────────────────────────────────────────────
static WalletConfig cfg;

static bool derive_and_display(uint32_t idx) {
    uint8_t key[33], chain[32];
    if (!bip32DerivePublic(cfg.xpubKey, cfg.xpubChain, 0,   key, chain)) return false;
    if (!bip32DerivePublic(key,          chain,          idx, key, chain)) return false;
    char addr[128] = {0};
    switch (cfg.addrType) {
        case 44: btcLegacyAddress(key, addr);  break;
        case 86: btcTaprootAddress(key, addr); break;
        default: btcSegwitAddress(key, addr);  break;
    }
    show_address(addr);
    return true;
}

// ── Button hold detection ─────────────────────────────────────────────────────
static bool btn_held(uint pin) {
    if (gpio_get(pin)) return false;   // not pressed (active LOW)
    absolute_time_t t = get_absolute_time();
    while (!gpio_get(pin)) {
        if (absolute_time_diff_us(t, get_absolute_time()) >= HOLD_MS * 1000)
            return true;
        sleep_ms(10);
    }
    return false;
}

// ── Main ──────────────────────────────────────────────────────────────────────
int main(void) {
    stdio_init_all();

    // Init SPI for e-ink
    spi_init(spi0, 2000000);
    spi_set_format(spi0, 8, SPI_CPOL_0, SPI_CPHA_0, SPI_MSB_FIRST);
    gpio_set_function(0, GPIO_FUNC_SPI);  // RX  (MISO, not used but claim it)
    gpio_set_function(2, GPIO_FUNC_SPI);  // SCK
    gpio_set_function(3, GPIO_FUNC_SPI);  // TX  (MOSI)

    // Init display — shows immediately on battery
    epd.LDirInit();
    epd.HDirInit();

    show_text("BOOT", "Checking USB...");

    // configFSBegin: loads disk from flash, checks VBUS,
    // starts USB only if host present. Safe on battery.
    bool usb_mode = configFSBegin();

    show_text("BOOT", usb_mode ? "USB ready" : "Battery mode",
              "Loading config...");

    // Load address index from flash
    uint32_t addr_index = load_index();

    // Load wallet config from disk image
    if (!configLoad(&cfg)) {
        show_setup_screen();
        // In USB mode: stay alive so the user can edit config.txt
        // In battery mode: nothing to show, sleep forever
        while (true) {
            if (usb_mode) configPeriodicSave();
            sleep_ms(100);
        }
    }

    // Show current address
    derive_and_display(addr_index);

    // Init buttons
    gpio_init(BTN_A); gpio_set_dir(BTN_A, GPIO_IN); gpio_pull_up(BTN_A);
    gpio_init(BTN_B); gpio_set_dir(BTN_B, GPIO_IN); gpio_pull_up(BTN_B);

    // ── Main loop ─────────────────────────────────────────────────────────────
    while (true) {
        if (usb_mode) configPeriodicSave();

        if (btn_held(BTN_A)) {
            addr_index++;
            save_index(addr_index);
            derive_and_display(addr_index);
            sleep_ms(300);
        }

        if (btn_held(BTN_B)) {
            addr_index = 0;
            save_index(addr_index);
            derive_and_display(addr_index);
            sleep_ms(300);
        }

        sleep_ms(20);
    }
}

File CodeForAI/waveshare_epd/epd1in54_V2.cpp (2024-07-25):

/*****************************************************************************
* | File      	:   epd1in54_V2.cpp
* | Author      :   Waveshare team
* | Function    :   1.54inch e-paper V2
* | Info        :
*----------------
* |	This version:   V1.0
* | Date        :   2019-06-24
* | Info        :
#
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
******************************************************************************/
#include <stdlib.h>
#include "epd1in54_V2.h"


// waveform full refresh
unsigned char WF_Full_1IN54[159] =
{											
0x80,	0x48,	0x40,	0x0,	0x0,	0x0,	0x0,	0x0,	0x0,	0x0,	0x0,	0x0,
0x40,	0x48,	0x80,	0x0,	0x0,	0x0,	0x0,	0x0,	0x0,	0x0,	0x0,	0x0,
0x80,	0x48,	0x40,	0x0,	0x0,	0x0,	0x0,	0x0,	0x0,	0x0,	0x0,	0x0,
0x40,	0x48,	0x80,	0x0,	0x0,	0x0,	0x0,	0x0,	0x0,	0x0,	0x0,	0x0,
0x0,	0x0,	0x0,	0x0,	0x0,	0x0,	0x0,	0x0,	0x0,	0x0,	0x0,	0x0,
0xA,	0x0,	0x0,	0x0,	0x0,	0x0,	0x0,					
0x8,	0x1,	0x0,	0x8,	0x1,	0x0,	0x2,					
0xA,	0x0,	0x0,	0x0,	0x0,	0x0,	0x0,					
0x0,	0x0,	0x0,	0x0,	0x0,	0x0,	0x0,					
0x0,	0x0,	0x0,	0x0,	0x0,	0x0,	0x0,					
0x0,	0x0,	0x0,	0x0,	0x0,	0x0,	0x0,					
0x0,	0x0,	0x0,	0x0,	0x0,	0x0,	0x0,					
0x0,	0x0,	0x0,	0x0,	0x0,	0x0,	0x0,					
0x0,	0x0,	0x0,	0x0,	0x0,	0x0,	0x0,					
0x0,	0x0,	0x0,	0x0,	0x0,	0x0,	0x0,					
0x0,	0x0,	0x0,	0x0,	0x0,	0x0,	0x0,					
0x0,	0x0,	0x0,	0x0,	0x0,	0x0,	0x0,					
0x22,	0x22,	0x22,	0x22,	0x22,	0x22,	0x0,	0x0,	0x0,			
0x22,	0x17,	0x41,	0x0,	0x32,	0x20
};

// waveform partial refresh(fast)
unsigned char WF_PARTIAL_1IN54_0[159] =
{
0x0,0x40,0x0,0x0,0x0,0x0,0x0,0x0,0x0,0x0,0x0,0x0,
0x80,0x80,0x0,0x0,0x0,0x0,0x0,0x0,0x0,0x0,0x0,0x0,
0x40,0x40,0x0,0x0,0x0,0x0,0x0,0x0,0x0,0x0,0x0,0x0,
0x0,0x80,0x0,0x0,0x0,0x0,0x0,0x0,0x0,0x0,0x0,0x0,
0x0,0x0,0x0,0x0,0x0,0x0,0x0,0x0,0x0,0x0,0x0,0x0,
0xF,0x0,0x0,0x0,0x0,0x0,0x0,
0x1,0x1,0x0,0x0,0x0,0x0,0x0,
0x0,0x0,0x0,0x0,0x0,0x0,0x0,
0x0,0x0,0x0,0x0,0x0,0x0,0x0,
0x0,0x0,0x0,0x0,0x0,0x0,0x0,
0x0,0x0,0x0,0x0,0x0,0x0,0x0,
0x0,0x0,0x0,0x0,0x0,0x0,0x0,
0x0,0x0,0x0,0x0,0x0,0x0,0x0,
0x0,0x0,0x0,0x0,0x0,0x0,0x0,
0x0,0x0,0x0,0x0,0x0,0x0,0x0,
0x0,0x0,0x0,0x0,0x0,0x0,0x0,
0x0,0x0,0x0,0x0,0x0,0x0,0x0,
0x22,0x22,0x22,0x22,0x22,0x22,0x0,0x0,0x0,
0x02,0x17,0x41,0xB0,0x32,0x28,
};

Epd::~Epd()
{
};

Epd::Epd()
{
	reset_pin = RST_PIN;
	dc_pin = DC_PIN;
	cs_pin = CS_PIN;
	busy_pin = BUSY_PIN;
	width = EPD_WIDTH;
	height = EPD_HEIGHT;
};

/**
 *  @brief: basic function for sending commands
 */
void Epd::SendCommand(unsigned char command)
{
	DigitalWrite(dc_pin, LOW);
	SpiTransfer(command);
}

/**
 *  @brief: basic function for sending data
 */
void Epd::SendData(unsigned char data)
{
	DigitalWrite(dc_pin, HIGH);
	SpiTransfer(data);
}

/**
 *  @brief: Wait until the busy_pin goes HIGH
 */
void Epd::WaitUntilIdle(void)
{
	while(DigitalRead(busy_pin) == 1) {      //LOW: idle, HIGH: busy
		DelayMs(100);
	}
	DelayMs(200);
}

void Epd::Lut(unsigned char* lut)
{
	SendCommand(0x32);
	for(unsigned char i=0; i<153; i++)
		SendData(lut[i]);
	WaitUntilIdle();
}

void Epd::SetLut(unsigned char* lut)
{
	Lut(lut);
	
    SendCommand(0x3f);
    SendData(lut[153]);
	
    SendCommand(0x03);
    SendData(lut[154]);
	
    SendCommand(0x04);
    SendData(lut[155]);
	SendData(lut[156]);
	SendData(lut[157]);
	
	SendCommand(0x2c);
    SendData(lut[158]);
}

// High Direction
int Epd::HDirInit(void)
{
	/* this calls the peripheral hardware interface, see epdif */
	if (IfInit() != 0) {
		return -1;
	}
	/* EPD hardware init start */
	Reset();

	WaitUntilIdle();
	SendCommand(0x12);  //SWRESET
	WaitUntilIdle();

	SendCommand(0x01); //Driver output control
	SendData(0xC7);
	SendData(0x00);
	SendData(0x01);

	SendCommand(0x11); //data entry mode
	SendData(0x01);

	SendCommand(0x44); //set Ram-X address start/end position
	SendData(0x00);
	SendData(0x18);    //0x0C-->(18+1)*8=200

	SendCommand(0x45); //set Ram-Y address start/end position
	SendData(0xC7);   //0xC7-->(199+1)=200
	SendData(0x00);
	SendData(0x00);
	SendData(0x00);

	SendCommand(0x3C); //BorderWavefrom
	SendData(0x01);

	SendCommand(0x18);
	SendData(0x80);

	SendCommand(0x22); // //Load Temperature and waveform setting.
	SendData(0XB1);
	SendCommand(0x20);

	SendCommand(0x4E);   // set RAM x address count to 0;
	SendData(0x00);
	SendCommand(0x4F);   // set RAM y address count to 0X199;
	SendData(0xC7);
	SendData(0x00);
	WaitUntilIdle();

	SetLut(WF_Full_1IN54);
	/* EPD hardware init end */

	return 0;
}

// Low Direction
int Epd::LDirInit(void)
{
	/* this calls the peripheral hardware interface, see epdif */
	if (IfInit() != 0) {
		return -1;
	}
	/* EPD hardware init start */
	Reset();

	WaitUntilIdle();
	SendCommand(0x12);  //SWRESET
	WaitUntilIdle();

	SendCommand(0x01); //Driver output control
	SendData(0xC7);
	SendData(0x00);
	SendData(0x00);

	SendCommand(0x11); //data entry mode
	SendData(0x03);

  SendCommand(0x44);
  /* x point must be the multiple of 8 or the last 3 bits will be ignored */
  SendData((0 >> 3) & 0xFF);
  SendData((199 >> 3) & 0xFF);
  SendCommand(0x45);
  SendData(0 & 0xFF);
  SendData((0 >> 8) & 0xFF);
  SendData(199 & 0xFF);
  SendData((199 >> 8) & 0xFF);

	SendCommand(0x3C); //BorderWavefrom
	SendData(0x01);

	SendCommand(0x18);
	SendData(0x80);

	SendCommand(0x22); // //Load Temperature and waveform setting.
	SendData(0XB1);
	SendCommand(0x20);

	SendCommand(0x4E);   // set RAM x address count to 0;
	SendData(0x00);
	SendCommand(0x4F);   // set RAM y address count to 0X199;
	SendData(0xC7);
	SendData(0x00);
	WaitUntilIdle();

	SetLut(WF_Full_1IN54);
	/* EPD hardware init end */

	return 0;
}


/**
 *  @brief: module reset.
 *          often used to awaken the module in deep sleep,
 *          see Epd::Sleep();
 */
void Epd::Reset(void)
{
  
	DigitalWrite(reset_pin, HIGH);
	DelayMs(20);
	DigitalWrite(reset_pin, LOW);                //module reset
	DelayMs(5);
	DigitalWrite(reset_pin, HIGH);
	DelayMs(20);
  
}

void Epd::Clear(void)
{
	int w, h;
	w = (EPD_WIDTH % 8 == 0)? (EPD_WIDTH / 8 ): (EPD_WIDTH / 8 + 1);
	h = EPD_HEIGHT;
 
	SendCommand(0x24);
	for (int j = 0; j < h; j++) {
		for (int i = 0; i < w; i++) {
			SendData(0xff);
		}
	}
	SendCommand(0x26);
	for (int j = 0; j < h; j++) {
		for (int i = 0; i < w; i++) {
			SendData(0xff);
		}
	}
	//DISPLAY REFRESH
	DisplayFrame();
}

void Epd::Display(const unsigned char* frame_buffer)
{
	int w = (EPD_WIDTH % 8 == 0)? (EPD_WIDTH / 8 ): (EPD_WIDTH / 8 + 1);
	int h = EPD_HEIGHT;

	if (frame_buffer != NULL) {
		SendCommand(0x24);
		for (int j = 0; j < h; j++) {
			for (int i = 0; i < w; i++) {
				SendData(pgm_read_byte(&frame_buffer[i + j * w]));
			}
		}
	}

	//DISPLAY REFRESH
	DisplayFrame();
}
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
